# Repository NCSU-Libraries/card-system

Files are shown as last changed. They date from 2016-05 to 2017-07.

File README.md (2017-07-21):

# Card System
Regulates access to DH Hill Library Makerspace, restricted to NC State University students, faculty and staff with campus ID cards. 

This repository includes Python code running on the system as well as electrical and mechanical design files.

## System Overview
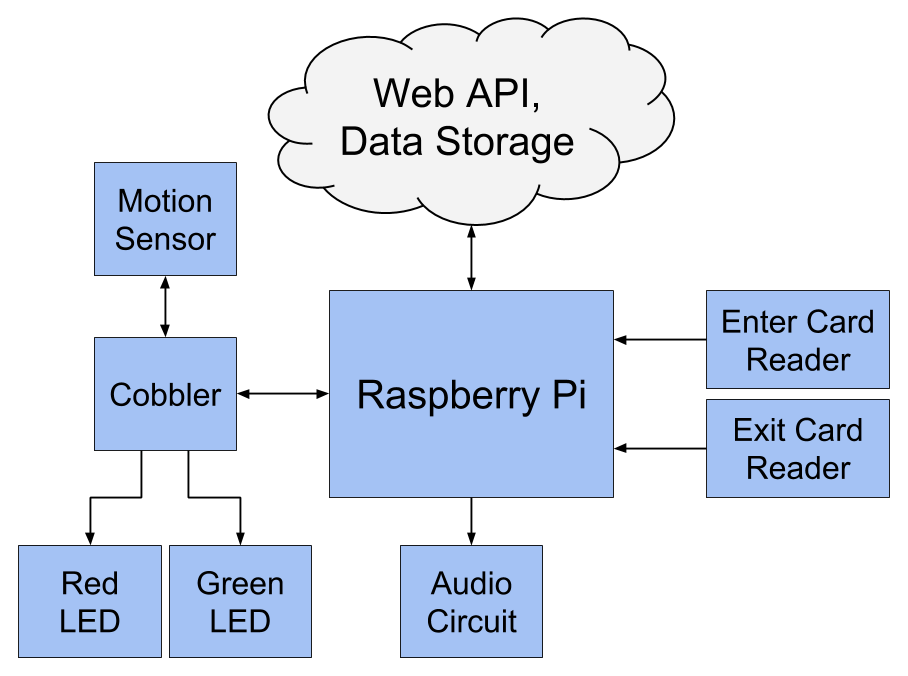
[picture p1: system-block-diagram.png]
System block diagram


The system comprises a Raspberry Pi with touchscreen, magnetic stripe card readers, a laser-cut enclosure produced in-house, a circuit board produced in-house, and associated electronics. It interacts with a web API (also produced in the Library) to authenticate users. The Pi runs a modified version of Raspbian Linux provided by Adafruit for use with their PiTFT touchscreens.

Users sign into the space by swiping their campus ID card on the entry card reader. The system accesses a database of users with the SpaceAuth API to check for the user's access privileges. If the user has access, they are greeted with a green light and an "access granted" from the speaker; otherwise, a red light and "access denied". The system also has a motion sensor (PIR) which, when triggered, triggers the system to deny access.

## Bill of Materials
| Item  | Quantity  | Link  |
| ----- | --- | ----- |
Raspberry Pi 2 Model B | 1 | https://www.raspberrypi.org/products/raspberry-pi-2-model-b/
PiTFT Plus 3.5" 480x320 | 1 | https://www.adafruit.com/products/2441
Assorted Terminal Blocks | - | https://www.adafruit.com/products/2234
ID TECH MiniMag Duo IDMB-354133B | 2 | http://idtechproducts.com/products/swipe-reader-writers/minimag-ii-compact-intelligent-magstripe-reader
Panel Monunt USB Port | 3 | https://www.adafruit.com/product/908
Panel Mount Ethernet Port | 1 | https://www.adafruit.com/products/909
Panel Mount 2.1mm Barrel Jack | 1 | https://www.adafruit.com/products/610
PIR Sensor | 1 | https://www.adafruit.com/products/189
330R Resistors | 2 | https://www.sparkfun.com/products/11507
10mm Green LED | 1 | https://www.sparkfun.com/products/10633
10mm Red LED | 1 | https://www.sparkfun.com/products/10632
3" 8 Ohm Speaker | 1 | https://www.adafruit.com/products/1313
3.5mm Stereo Plug | 1 | https://www.adafruit.com/products/1700
Mono Amplifier | 1 | https://www.sparkfun.com/products/11044
10K Logarithmic Potentiometer | 1 | https://www.sparkfun.com/products/9940
Male Machine Pin Headers | 1 | https://www.sparkfun.com/products/117
Female Machine Pin Headers | 1 | https://www.sparkfun.com/products/743
2x13 shrouded header | 1 | https://www.sparkfun.com/products/retired/11490
6-wire Ribbon Cable | 1 | https://www.sparkfun.com/products/10651
2x6 Crimp connector | 2 | https://www.sparkfun.com/products/10651
2x6 Shrouded Header | 1 | https://www.sparkfun.com/products/10877

## Author
Aaron Arthur, adarthur@ncsu.edu

## Project Collaborators
Bret Davidson  (author of Space Auth API)

Adam Rogers (project requirements + management)

Jack Twiddy (PCB and enclosure fabrication)

Augustus Vieweg (code contribution)

## LICENSE
MIT License

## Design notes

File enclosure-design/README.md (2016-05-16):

#Enclosure Design
##Version 1
The first card system enclosure was made of laser-cut bamboo panels, bolted together.
version 1

##Version 2
The second enclosure is made of laser-cut acrylic panels (black and clear), glued together.
version 2

##Inside Version 2
There is no bottom panel to the enclosure, allowing for easy access to the circuitry inside.
version 2

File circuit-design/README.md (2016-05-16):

#Circuit Design
##Main Board Schematic
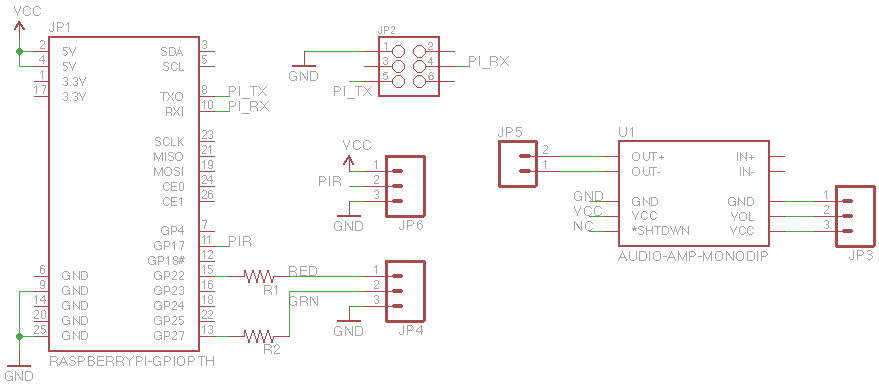
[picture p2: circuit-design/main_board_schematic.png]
main board schematic


##Main Board Layout
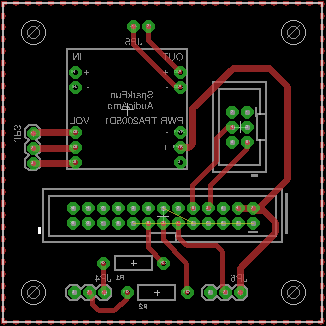
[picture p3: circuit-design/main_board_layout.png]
main board layout


##Ribbon to FTDI Schematic
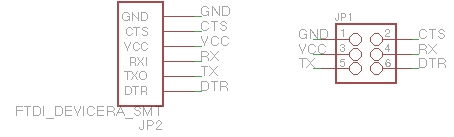
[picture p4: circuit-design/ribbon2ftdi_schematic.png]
ribbon2ftdi schematic


##Ribbon to FTDI Layout
ribbon2ftdi schematic

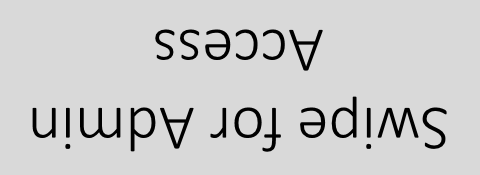
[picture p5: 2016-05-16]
on-system-content/admin_swipe.gif

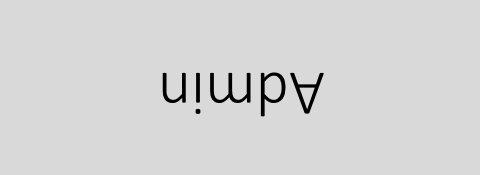
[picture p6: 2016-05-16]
on-system-content/admin.gif

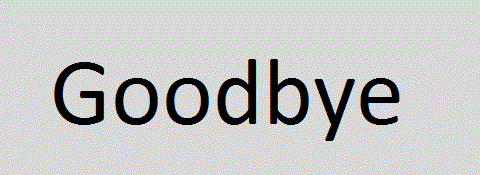
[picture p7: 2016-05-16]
on-system-content/goodbye.gif

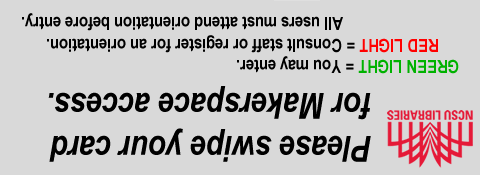
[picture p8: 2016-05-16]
on-system-content/swipe.gif

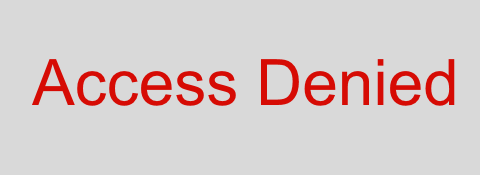
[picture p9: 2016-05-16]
on-system-content/denied.gif

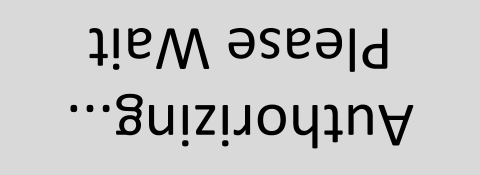
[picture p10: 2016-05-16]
on-system-content/authorizing.gif

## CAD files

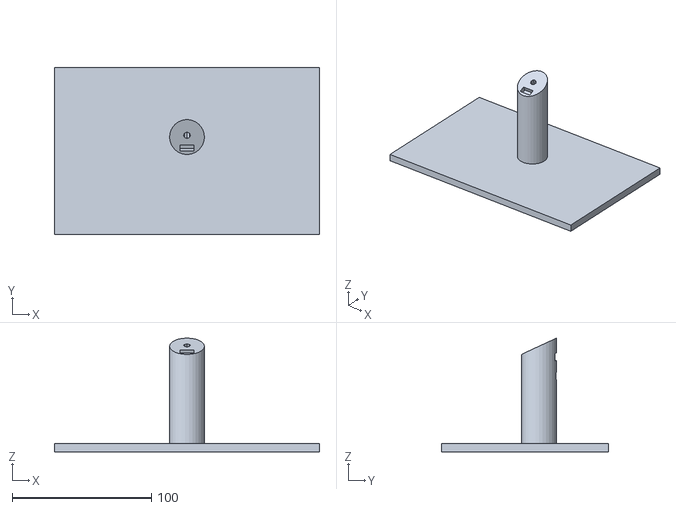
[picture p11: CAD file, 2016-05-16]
enclosure-design/swipe_out_stand.stl
190.0 x 120.0 x 81.5

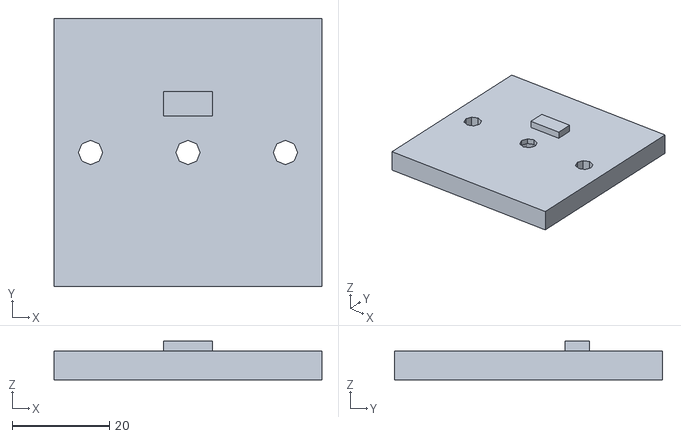
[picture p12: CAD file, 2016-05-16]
enclosure-design/swip_out_mount.stl
55.0 x 55.0 x 8.00

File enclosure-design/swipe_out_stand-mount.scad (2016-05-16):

// Makerspace Card System
// Stand and mount for swipe-out panel
// Print the stand and mount separately.
// The printable implementations of the models are at the bottom of the file.

// Hardware dimensions
screw_d = 5;

// Base dimensions
base_l = 190;
base_w = 120;
base_t = 6;

// Column dimensions
col_d = 25;
col_h = 80;
col_offset = col_h/2 + base_t/2;

// Mount dimensions
mount_angle = 25;
mount_l = 55;
mount_w = 55;
mount_t = 6;
mount_form_t = mount_t*3;
mount_offset = col_h + base_t - 10;

// Nub dimensions
nub_l = 10;
nub_w = 5;
nub_t = 5;

// Explosion factor
e_factor = 0;

// Mount module
module mount()
{
	difference()
	{
		cube([mount_l,mount_w,mount_t], center=true);
		for(i=[-20,20])
			translate([i,0,0]) cylinder(d=screw_d,h=mount_t+2, center=true);
	}	
	translate([0,-10,-mount_t/2+nub_t/2-2])
		cube([nub_l,nub_w,nub_t], center=true);

}

// Mount form for trimming the column
module mount_form()
{
	translate([0,0,mount_form_t/2-mount_t/2])
		cube([mount_l-1,mount_w-1,mount_form_t], center=true);
	cylinder(d=screw_d,h=60, center=true); // hole for screw
	translate([0,0,-15]) hull()
	{
		translate([0,0,0]) cylinder(d=screw_d*2,h=screw_d,center=true); //space for nut
		translate([0,7,0]) cylinder(d=screw_d*2,h=screw_d,center=true); //space for nut
	}
	translate([0,-10,-mount_t+nub_t/2-1])
			cube([nub_l,nub_w,nub_t], center=true);

}

// Base module
module base()
{
	translate([0,-10,0])
		cube([base_l,base_w,base_t], center=true);
}

module curved_base()
{
	translate([0,-32,0])
	difference()
	{
		scale([1.7,.9,1])
			cylinder(d=base_l,h=base_t, center=true);
		translate([0,-base_w/3,0])
			scale([1.4,.9,1.2])
				cylinder(d=base_l,h=base_t, center=true);
	}	
}

// Column module
module column()
{
	translate([0,0,col_offset])
		cylinder(d=col_d,h=col_h, center=true);
}

// Demonstrate stand model
module exploded_demo()
{
	rotate([mount_angle,0,0])
	{
		translate([0,0,e_factor]) 
			difference() // mount
			{
				mount();
				cylinder(d=screw_d,h=50, center=true); // arbitrary length; hole for screw
				translate([0,0,-mount_t/4]) cylinder(d=screw_d*2,h=mount_t); // for screw head
			}
		translate([0,-10,mount_t/2+1+e_factor*2])
		{
			%cube([200,150,2], center=true); // panel model; use % in front to make translucent
			translate([50,-120,0]) cube([2,90,10], center=true);
		}
	}
	difference() // base + column - mount_form
	{
		translate([0,0,-mount_offset]) 
		{
			column();
			base();
		}
		rotate([mount_angle,0,0])
			mount_form();
	}
}

// Final Models
module final_mount()
{
	difference() // mount
	{
		mount();
		cylinder(d=screw_d,h=50, center=true); // arbitrary length; hole for screw
		translate([0,0,-mount_t/4]) cylinder(d=screw_d*2,h=mount_t); // for screw head
	}
}

module final_stand()
{
	difference() // base + column - mount_form
	{
		translate([0,0,-mount_offset]) 
		{
			column();
			base();
		}
		rotate([mount_angle,0,0])
			mount_form();
	}
}


// Place things to print here
//final_stand();
final_mount();

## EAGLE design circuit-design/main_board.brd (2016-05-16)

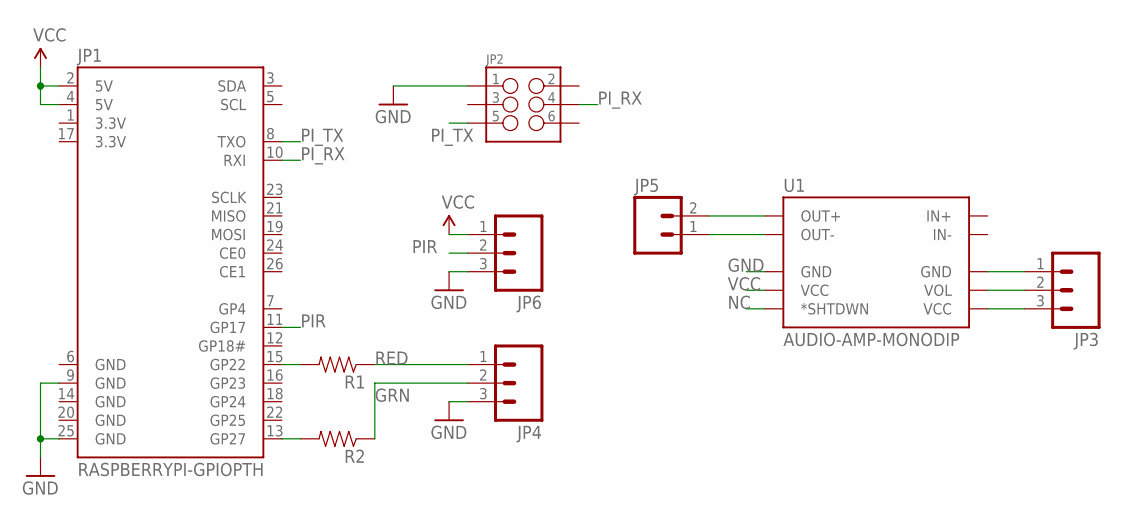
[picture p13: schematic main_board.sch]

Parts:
JP1: RASPBERRYPI-GPIOPTH; 2X13-SHROUDED
JP2: M03X2SHROUD; 2X3-SHROUDED
JP3, JP4, JP6: M03PTH; 1X03
JP5: M021X02_NO_SILK; 1X02_NO_SILK
R1, R2: RESISTORPTH-1/4W; AXIAL-0.4
U1: AUDIO-AMP-MONODIP; AUDIO-AMP-MONO

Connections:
3.3V: JP1.1 (3.3V), JP1.17 (3.3V)
GND: JP1.6 (GND), JP1.9 (GND), JP1.14 (GND), JP1.20 (GND), JP1.25 (GND), JP2.1, JP4.3, JP6.3, U1.PWR- (GND)
GRN: JP4.2, R2.P$1 (1)
unnamed: JP5.2, U1.OUT+
unnamed: JP5.1, U1.OUT-
unnamed: JP1.15 (GP22), R1.P$2 (2)
unnamed: JP1.13 (GP27), R2.P$2 (2)
unnamed: JP3.1, U1.VOL- (GND)
unnamed: JP3.2, U1.VOL
unnamed: JP3.3, U1.VOL+ (VCC)
NC: U1.S (*SHTDWN)
PIR: JP1.11 (GP17), JP6.2
PI_RX: JP1.10 (RXI), JP2.4
PI_TX: JP1.8 (TXO), JP2.5
RED: JP4.1, R1.P$1 (1)
VCC: JP1.2 (5V), JP1.4 (5V), JP6.1, U1.PWR+ (VCC)

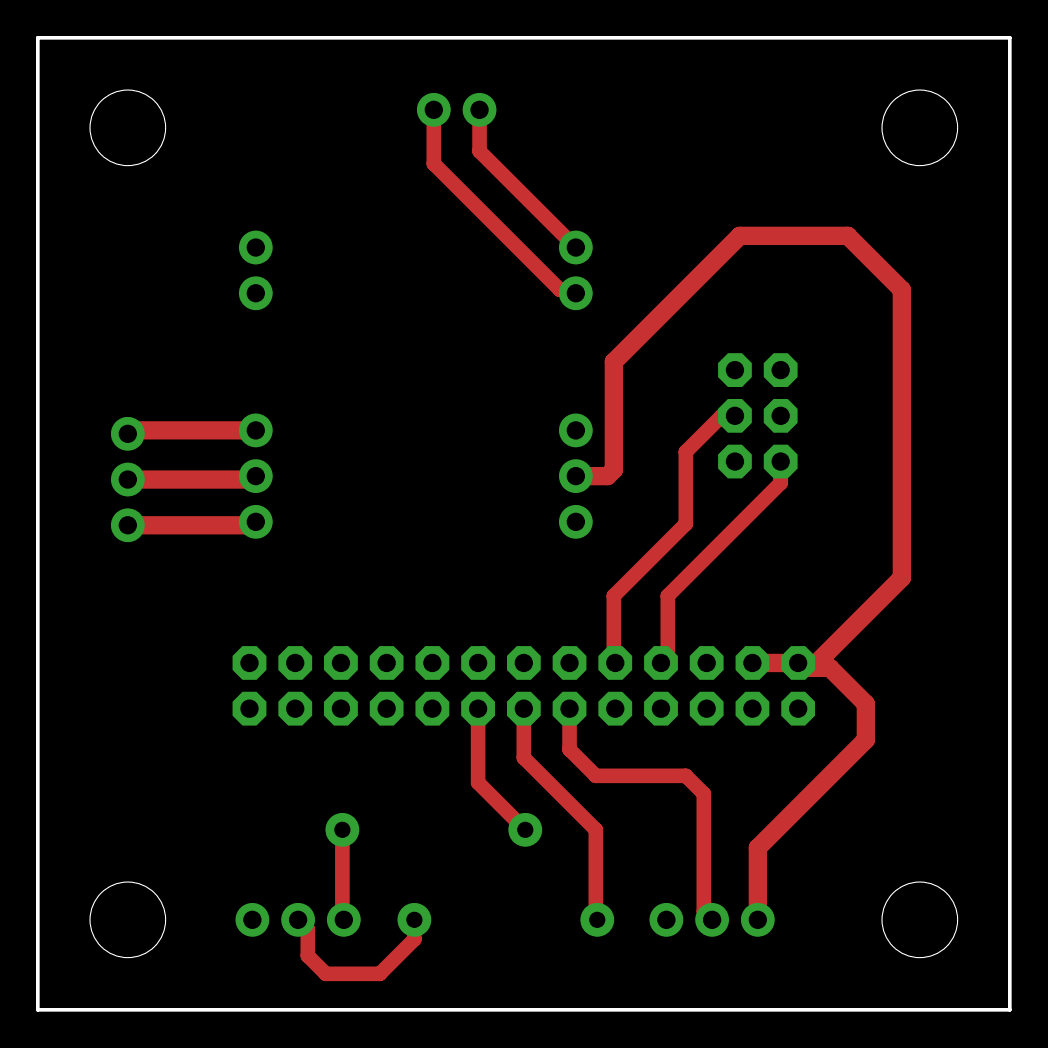
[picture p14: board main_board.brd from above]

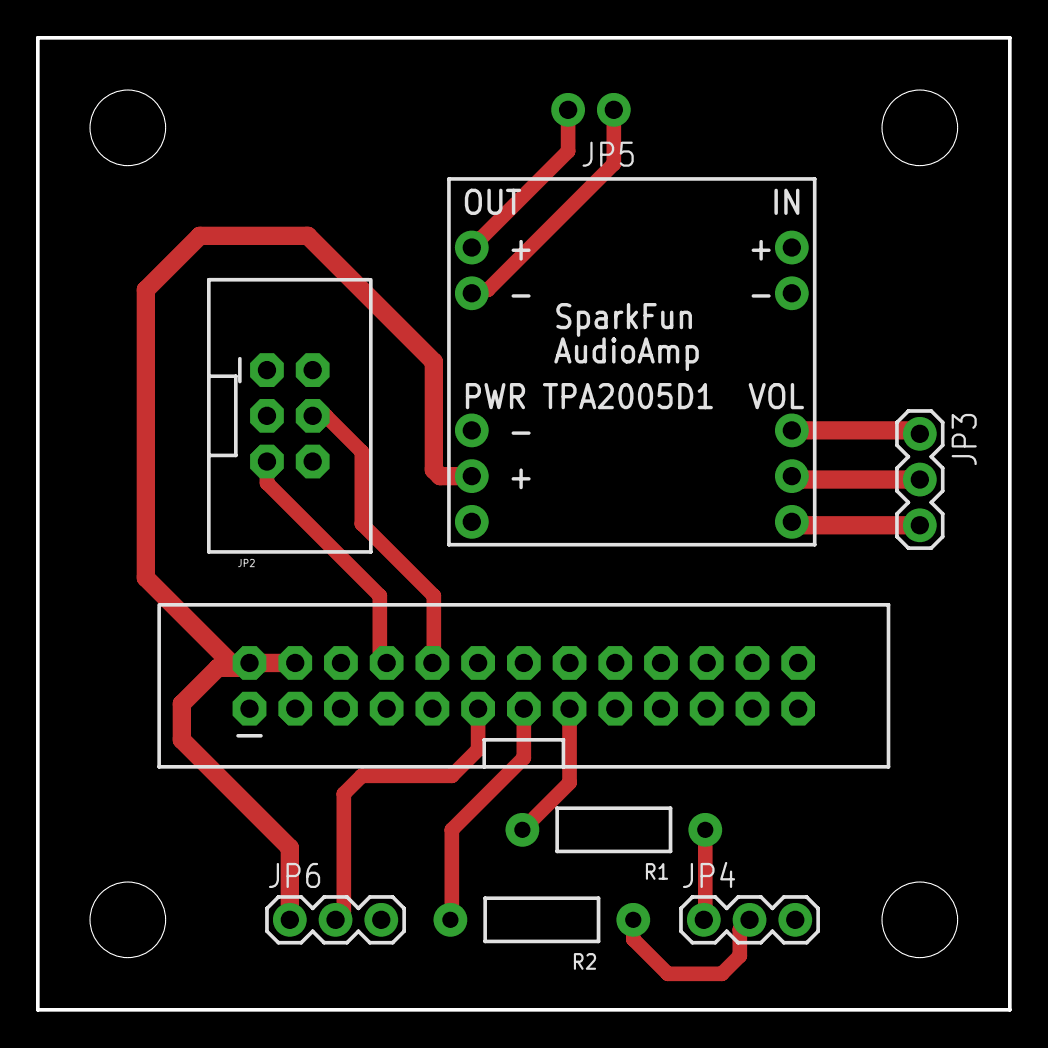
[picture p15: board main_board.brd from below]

Board: 2 copper layers, 54.0 x 54.0 mm, 9 parts (9 on the bottom side), 15 nets.

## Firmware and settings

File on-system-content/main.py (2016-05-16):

#!/usr/bin/python
# -*- coding: utf-8 -*-
#
# main.py
#
# Main (only) script the user must execute.
#  - Initializes hardware
#  - Checks connection to Google Sheets
#  - Starts TKinter
#  - Initializes MyGui and MyController classes

import time
import gspread
import json
import socket
import constants
from config import Data_Spreadsheet, Credentials_File
import RPi.GPIO as GPIO
import os
from gui import *
from controller import *
from oauth2client.client import GoogleCredentials

#---------- Main Script ----------

# setup GPIO using Board numbering
GPIO.setmode(GPIO.BCM)

# initialize GPIO pins and blink the lights once
GPIO.setup(greenPin, GPIO.OUT)
GPIO.setup(redPin, GPIO.OUT)
GPIO.setup(pirPin, GPIO.IN, pull_up_down = GPIO.PUD_DOWN)

GPIO.output(greenPin, True)
GPIO.output(redPin, True)
time.sleep(0.5)
GPIO.output(greenPin, False)
GPIO.output(redPin, False)

os.environ['GOOGLE_APPLICATION_CREDENTIALS'] = Credentials_File

credentials = GoogleCredentials.get_application_default()
credentials = credentials.create_scoped(['https://spreadsheets.google.com/feeds'])

print "\n"*50
print "Starting Up"
try: 
	root = Tk()
	mycontroller = MyController()
	mygui = MyGui(root, mycontroller)
	mycontroller.enableMotionDetect()
	print "Connecting to Google"
	gc = gspread.authorize(credentials)
	print "Opening sheet"
	wks = gc.open(Data_Spreadsheet).sheet1
	print "Set up and ready to go"
	root.mainloop()
	
except socket.gaierror:
	print "Could not connect to Google"
	root.mainloop()
except:
	print "Some error occurred"
	print sys.exc_info()

finally:
	print "Finished"
	GPIO.cleanup()

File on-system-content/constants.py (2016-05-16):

#!/usr/bin/python
# -*- coding: utf-8 -*-
#
# constants.py
#
# Constants and global variables to be used across multiple files

# to pass to denyAccess/grantAccess
playSong = 1
muteSong = 0

# GPIO pins used
greenPin = 27
redPin = 22
pirPin = 17

# other constants
accessSleep = 4 # seconds to leave an LED on
imageSleep = 2500 # milliseconds between image refreshes
motionSleep = .25 # seconds to wait after motion is detected
serverSpinPeriod = 90000 # milliseconds between calls to spinServer() in GUI
directory = '/home/pi/card_system/' # location of all .py .gif and .wav files

# Global variables
Todays_Date = ''

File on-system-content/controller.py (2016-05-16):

#!/usr/bin/python
# -*- coding: utf-8 -*-
#
# controller.py
#
# Home to the MyController class, used for:
#  - Interacting directly with hardware: LEDs, PIR sensor
#  - Interacting directly with the SpaceAuth API and the datalogger script
#  - Checking IDs
#  - Granting/denying access

import time
import sys
import os
import subprocess
from constants import *
from config import *
import RPi.GPIO as GPIO
from urllib2 import urlopen, Request
from json import loads

class MyController:
	def __init__(self):
		print "Initializing controller"
		
		self.idList = []
		
	#---------- API Request ----------
	# Make an authorized request to the API using
	# the key found in constants.py
	def APIRequest(self, _url):
		_request = Request(_url, None, {'X-Api-Key':API_Key})
		return urlopen(_request)
				
	#---------- API Check Endorsement ----------
	# Endorsements are listed in a JSON file generated
	# by the web API.
	#
	# Arguments:
	#	user_id			: user id number to check
	#	endorsement_unique_name : unique name of endorsement in database 
	#	station			: station name ('enter', 'exit', etc.) in database
	# 
 	# Returns: 
	#	1 if user has endorsement, 0 otherwise
	#
	def APICheckEndorsement(self, user_id, endorsement_unique_name, station):
		try:
			endorsementsToParse = self.APIRequest(API_Users_URL + 
								user_id + 
								'/endorsements?station=' + 
								station).read()
		except Exception as e:
			print e
			print "Could not access server"
			return 0

		print endorsementsToParse
		parsedEndorsements = loads(endorsementsToParse)
		
		for endorsement in parsedEndorsements:
			if endorsement[Unique_Name_Key] == endorsement_unique_name:
				return 1
		
		return 0
		
	#---------- API Check Admin ----------
	# Returns 1 if user has admin access to the system, else 0.
	def APICheckAdmin(self, user_id):
		try:
			userToParse = self.APIRequest(API_Users_URL + user_id).read()
			parsedUser = loads(userToParse)
			if "admin" in parsedUser['role']:
				return 1
			else: 
				return 0
		except:
			print "Could not access server"
			return 0
		
	#---------- Check Date ----------
	# If today isn't the recorded date, erase the unique ID list
	# and set the date.
	def checkDate(self):
		global Todays_Date
		today = subprocess.check_output('date +"%D"', shell=True)
		today = today.strip()
		if Todays_Date != today:
			self.idList = []
			Todays_Date = today	
	
	# Get the current time
	def checkTime(self):
		timestamp = subprocess.check_output('date +"%H:%M"', shell=True)
		timestamp = timestamp.strip()
		
		return timestamp
		
	#---------- Controller Check ID ----------
	# See if the ID has space access and return True/False.
	# Append the swipe record to the Google Sheet.
	# Station: 0 for exit, 1 for enter
	def checkId(self, patronId, station):
		uniqueId = 0
		accessed = 0

		# Assign statin string
		if station == 1:
			stationStr = "enter"
		elif station == 0:
			stationStr = "exit"
		else: 
			return False

		accessGranted = self.APICheckEndorsement(patronId, Space_Access_Unique_Name, stationStr)
		if(accessGranted): accessGrantedBool = True
		else: 
			accessGrantedBool = False
			print patronId
		
		self.checkDate()
		
		# See if ID is unique for today
		# and if access was granted
		if patronId not in self.idList: 
			uniqueId = 1
			self.idList.append(patronId)
		else: uniqueId = 0

		# Get the current time
		timestamp = self.checkTime()
		
		# Build the shell command to run the datalogger
		dataloggerString = 'python '+directory+'datalogger.py "'+Todays_Date+'" "'+timestamp+'" "'+str(accessGranted)+'" "'+str(uniqueId)+'" "'+str(station)+'"&'
		
		subprocess.Popen(dataloggerString, shell=True)
		
		return accessGrantedBool
		
	#---------- Log Swipe Out ----------
	#
	#
	def logSwipeOut(self):

		self.checkDate()
		timestamp = self.checkTime()
		
		dataloggerString = 'python '+directory+'datalogger.py "'+Todays_Date+'" "'+timestamp+'" "'+'"1"'+'" "'+'"0"'+'" "'+'"0"'+'"&' 
		
		subprocess.Popen(dataloggerString, shell=True)
	
	#---------- Deny Access ----------
	# Play sad tune and blink the red light.
	# Disable motion detect for ~2.5 seconds.
	def denyAccess(self, toPlay):
		self.disableMotionDetect()
		GPIO.output(redPin, True)
		if toPlay:
			os.system('aplay ' + directory + 'sad.wav &')
		time.sleep(accessSleep)
		self.enableMotionDetect()
		GPIO.output(redPin, False)
		print "Access Denied"
		
	#---------- Grant Access ----------
	# Play happy tune and blink the green light.
	# Disable motion detect for ~4 seconds.
	def grantAccess(self, toPlay, inOrOut):
		self.disableMotionDetect()
		GPIO.output(greenPin, True)
		if toPlay:
			if inOrOut:
				os.system('aplay ' + directory + 'happy.wav &')
			else:
				os.system('aplay ' + directory + 'goodbye.wav &')
		time.sleep(accessSleep)
		self.enableMotionDetect()
		GPIO.output(greenPin, False)
		print "Access Granted"
		
	# Turn a specific pin on
	def LEDOn(self, LEDPin):
		GPIO.output(LEDPin, True)
		
	# Turn a specific pin off
	def LEDOff(self, LEDPin):
		GPIO.output(LEDPin, False)

	#---------- Motion Detected ----------
	# When motion is detected, play a beeping sound
	# and flash the red LED
	def motionDetectCallback(self, pirPin):
		print "Motion Detected!"
		os.system('aplay ' + directory + 'sad.wav &')
		while GPIO.input(pirPin):
			GPIO.output(redPin, True)
			time.sleep(motionSleep)
			GPIO.output(redPin, False)
			time.sleep(motionSleep)
	
	# Turn on motion detection
	def enableMotionDetect(self):
		GPIO.add_event_detect(pirPin, GPIO.RISING)
		GPIO.add_event_callback(pirPin, self.motionDetectCallback)
		
	# Turn off motion detectoin
	def disableMotionDetect(self):
		GPIO.remove_event_detect(pirPin)

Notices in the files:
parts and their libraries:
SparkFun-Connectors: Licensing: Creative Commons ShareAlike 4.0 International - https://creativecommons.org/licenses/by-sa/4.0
